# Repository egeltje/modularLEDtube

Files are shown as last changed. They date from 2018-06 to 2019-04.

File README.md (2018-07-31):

# modularLEDtube
A stackable tube with ws2812 LED's that can be combined to create an organ-like 
sculpture and display various light effects.

https://www.pjrc.com/store/teensy32.html
https://www.pjrc.com/store/octo28_adaptor.html

2 x https://www.xxlstunt.nl/product/plexiglas-buis--geextrudeerd-148/
8 x https://www.xxlstunt.nl/product/afvoer-pvc-bocht-45---mof-spie-3/
8 x https://www.xxlstunt.nl/product/afvoer-pvc-t-stuk-90---verloop-mof-spie-5/
2 x https://www.xxlstunt.nl/product/afvoer-pvc-eindstuk-met-schroefdeksel--spie-5/
2 x https://www.xxlstunt.nl/product/afvoer-pvc-buis-sn4-1/

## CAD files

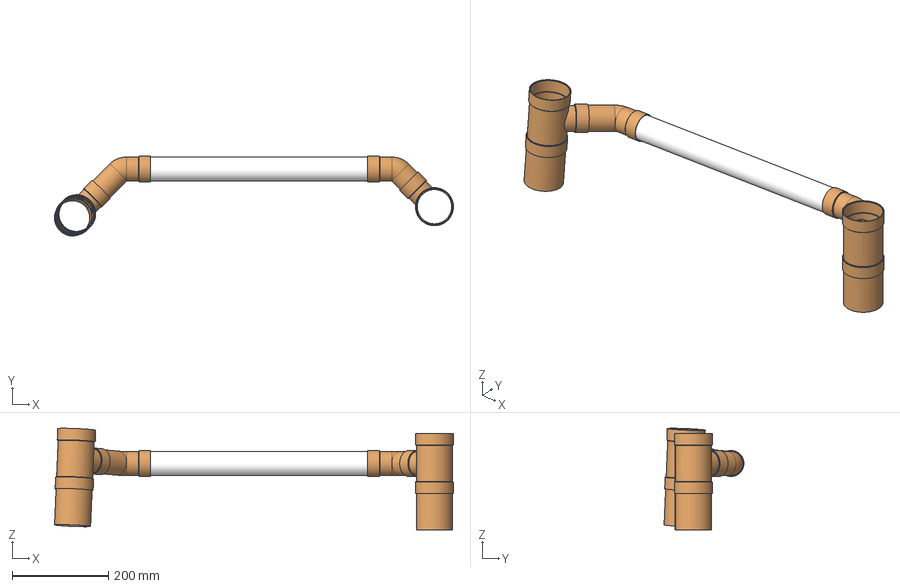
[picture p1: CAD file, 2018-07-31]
cad/overview.FCStd
827.3 x 165.8 x 210.6 mm
L_50_01
L_50_01001
tube_transparent_50x500_01
T_75x50_01
T_75x50_01001
tube_solid_75x100_01
tube_solid_75x100_01001

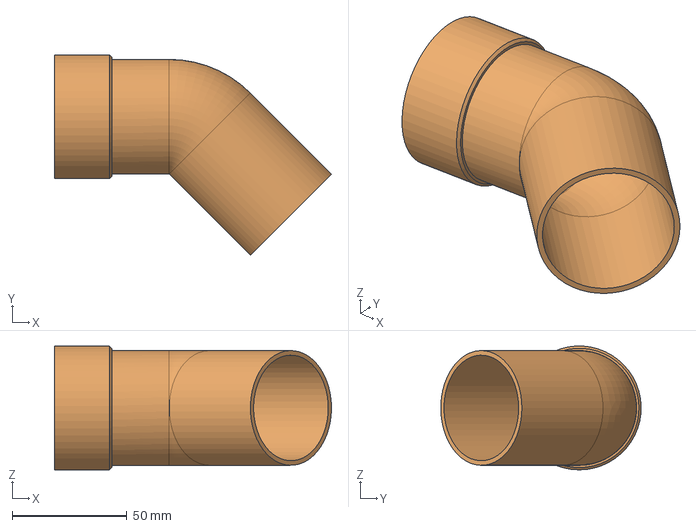
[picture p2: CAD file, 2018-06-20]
cad/L-50.FCStd
120.7 x 87.3 x 53.9 mm

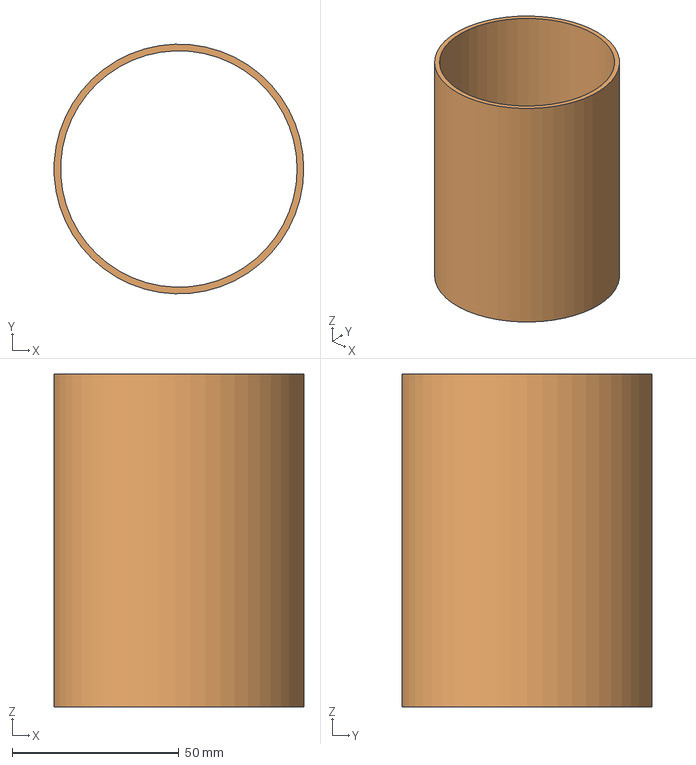
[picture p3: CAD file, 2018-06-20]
cad/tube-solid-75x100.FCStd
74.9 x 75.0 x 100.0 mm

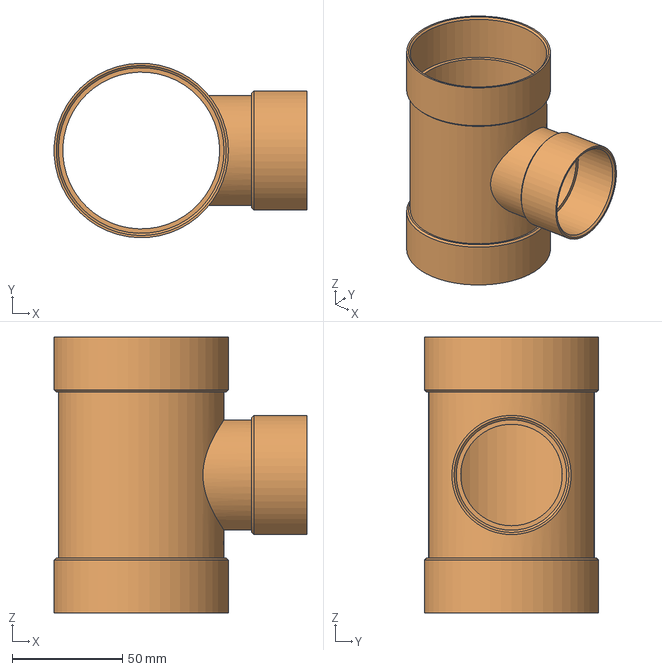
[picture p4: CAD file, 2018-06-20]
cad/T-75x50.FCStd
114.4 x 79.0 x 125.0 mm

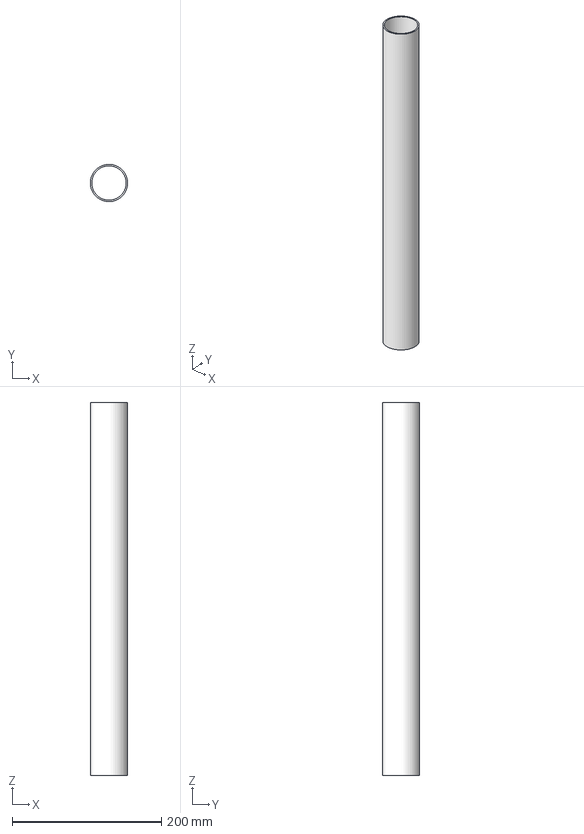
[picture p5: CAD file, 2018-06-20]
cad/tube-transparent-50x500.FCStd
50.0 x 50.0 x 500.0 mm

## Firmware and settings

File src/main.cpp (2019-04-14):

#include <Arduino.h>
#include "FastLED.h"
#include <stdint.h>
#include "main.h"

void setup() {
  // configure serial ports
  // Serial.begin(115200);
  // Serial1.begin(9600);

  // configure lED strips in FastLED array
  FastLED.addLeds<CHIPSET, LED_PIN0, COLOR_ORDER>(leds[0], NUM_LEDS).setCorrection( TypicalLEDStrip );
  FastLED.addLeds<CHIPSET, LED_PIN1, COLOR_ORDER>(leds[1], NUM_LEDS).setCorrection( TypicalLEDStrip );
  FastLED.addLeds<CHIPSET, LED_PIN2, COLOR_ORDER>(leds[2], NUM_LEDS).setCorrection( TypicalLEDStrip );
  FastLED.addLeds<CHIPSET, LED_PIN3, COLOR_ORDER>(leds[3], NUM_LEDS).setCorrection( TypicalLEDStrip );
  FastLED.addLeds<CHIPSET, LED_PIN4, COLOR_ORDER>(leds[4], NUM_LEDS).setCorrection( TypicalLEDStrip );
  FastLED.addLeds<CHIPSET, LED_PIN5, COLOR_ORDER>(leds[5], NUM_LEDS).setCorrection( TypicalLEDStrip );
  FastLED.addLeds<CHIPSET, LED_PIN6, COLOR_ORDER>(leds[6], NUM_LEDS).setCorrection( TypicalLEDStrip );
  FastLED.addLeds<CHIPSET, LED_PIN7, COLOR_ORDER>(leds[7], NUM_LEDS).setCorrection( TypicalLEDStrip );

  delay(100); // sanity delay

  // Initialize Perlin coordinates to some random values
  x = random16();
  y = random16();
  z = random16();
}

void loop()
{
  // Add entropy to random number generator; we use a lot of it.
  random16_add_entropy(random());

  EVERY_N_MILLISECONDS(FRAME_DELAY) {
    // read potmeters and determine state
    Param1 = ReadPot(POT_EFFECT);
    Param2 = ReadPot(POT_EFFECT_MOD1);
    Param3 = ReadPot(POT_EFFECT_MOD2);
    Param4 = ReadPot(POT_EFFECT_MOD3);
    State = ReadState(Param1);

    // run simulation frame depending on state
    switch (State) {
      case 2:
        Light(Param2, Param3, Param4);
        break;
      case 3:
        Color(Param2, Param3, Param4);
        break;
      case 4:
        Earth(Param2, Param3, Param4);
        break;
      case 5:
        Water(Param2, Param3, Param4);
        break;
      case 6:
        Fire(Param2, Param3, Param4);
        break;
      case 7:
        Air(Param2, Param3, Param4);
        break;
      default:
        Rainbow(Param2, Param3, Param4);
    }
    // display the calculated frame
    FastLED.show();
  }
}

void Light(uint8_t Param2, uint8_t Param3, uint8_t Param4) {
  // Param2 not used
  // Param3 not used
  // Param4 brightness
  uint8_t i, j;

  for (i = 0; i < NUM_STRIPS; i++) {
    for (j = 0; j < NUM_LEDS; j++) {
      leds[i][j] = 0xFFFFFF;
    }
  }
  FastLED.setBrightness(Param4);
}

void Color(uint8_t Param2, uint8_t Param3, uint8_t Param4) {
  // Param2 Hue
  // Param3 Saturation
  // Param4 Value
  uint8_t i, j;
  CRGB rgb;
  CHSV hsv(Param2, Param3, Param4);

  hsv2rgb_spectrum(hsv, rgb);

  for (i = 0; i < NUM_STRIPS; i++) {
    for (j = 0; j < NUM_LEDS; j++) {
      leds[i][j] = rgb;
    }
  }
}

void Earth(uint8_t Param2, uint8_t Param3, uint8_t Param4) {
  // Param2 Density
  // Param3 Level
  // Param4 Brightness
  static uint8_t solid[NUM_STRIPS][NUM_LEDS];
  uint8_t i, j;
  int iOffset, jOffset;

  for (i = 0; i < NUM_STRIPS; i++) {
    iOffset = i * Param2;
    for (j = 0; j < (NUM_LEDS / (255 / Param3)); j++) {
      jOffset = j * Param2;
      solid[i][j] = inoise8(x + iOffset, y + jOffset, (Param2 * 10));
    }
    for(j = 0; j < NUM_LEDS; j++) {
      leds[i][j] = ColorFromPalette((CRGBPalette16)earth_gp, solid[i][j]);
    }
  }
  FastLED.setBrightness(Param4);
}

void Water(uint8_t Param2, uint8_t Param3, uint8_t Param4) {
  // Param2 Waves
  // Param3 Level
  // Param4 Brightness
  static uint8_t liquid[NUM_STRIPS][NUM_LEDS];
  uint8_t i, j;
  int iOffset, jOffset;

  for (i = 0; i < NUM_STRIPS; i++) {
    iOffset = i * Param2;
    for (j = 0; j < (uint8_t)((Param2 * NUM_LEDS) / 255); j++) {
      jOffset = j * Param2;
      liquid[i][j] = inoise8(x + iOffset, y + jOffset, z);
    }
    for (j = (uint8_t)((Param3 * NUM_LEDS) / 255) + 1; j < NUM_LEDS; j++) {
      liquid[i][j] = 0;
    }
    z++; // move through the Perlin noise
    for(j = 0; j < NUM_LEDS; j++) {
      leds[i][j] = ColorFromPalette((CRGBPalette16)water_gp, liquid[i][j]);
    }
  }
  FastLED.setBrightness(Param4);
}

void Fire(uint8_t Param2, uint8_t Param3, uint8_t Param4) {
  // Param2 Sparkling
  // Param3 Cooling
  // Param4 brightness
  // Inspired by Fire2012 by Mark Kriegsman, July 2012
  // as part of "Five Elements" shown here: http://youtu.be/knWiGsmgycY

  static uint8_t heat[NUM_STRIPS][NUM_LEDS];
  uint8_t i, j;

  for (i = 0; i < NUM_STRIPS; i++) {
    // Step 1.  Cool down every cell a little
    for(j = 0; j < NUM_LEDS; j++) {
      heat[i][j] = qsub8(heat[i][j],  random8(0, ((Param3 * 10) / NUM_LEDS) + 2));
    }
    // Step 2.  Heat from each cell drifts 'up' and diffuses a little
    for(j = NUM_LEDS - 1; j >= 2; j--) {
      heat[i][j] = (heat[i][j - 1] + heat[i][j - 2] + heat[i][j - 2] ) / 3;
    }
    // Step 3.  Randomly ignite new 'sparks' of heat near the bottom
    if(random8() < Param2) {
      j = random8(7);
      heat[i][j] = qadd8(heat[i][j], random8(160,255));
    }
    // Step 4.  Map from heat cells to LED colors
    for(j = 0; j < NUM_LEDS; j++) {
      leds[i][j] = HeatColor(heat[i][j]);
//      leds[i][j] = ColorFromPalette((CRGBPalette16)fire_gp, heat[i][j]);
    }
  }
  FastLED.setBrightness(Param4);
}

void Air(uint8_t Param2, uint8_t Param3, uint8_t Param4) {
  // Param2 Bubbling
  // Param3 not used
  // Param4 Brightness
  static uint8_t gas[NUM_STRIPS][NUM_LEDS];
  uint8_t i, j;

  for (i = 0; i < NUM_STRIPS; i++) {
    // rise all bubbles
    for(j = NUM_LEDS - 1; j >= 1; j--) {
      gas[i][j] = gas[i][j - 1];
    }
    // Generate new bubbles at random
    if(random8() < (Param2/8)) {
      gas[i][0] = 0;
      gas[i][1] = 127;
      gas[i][2] = 255;
    }
    for(j = 0; j < NUM_LEDS; j++) {
      leds[i][j] = ColorFromPalette((CRGBPalette16)air_gp, gas[i][j]);
    }
  }
  FastLED.setBrightness(Param4);
}

void Rainbow(uint8_t Param2, uint8_t Param3, uint8_t Param4) {
  // Param2 not used
  // Param3 not used
  // Param4 Brightness
  static uint8_t Gradient;
  uint8_t i;

  if (Gradient < RAINBOW_STEP) {
    Gradient = 255;
  } else {
    Gradient -= RAINBOW_STEP;
  }

  for (i = 0; i < NUM_STRIPS; i++) {
    fill_rainbow(leds[i], NUM_LEDS, ((i * 20 + Gradient) % 255), 4);
  }
  FastLED.setBrightness(Param4);
}

uint16_t ReadPot(uint8_t Channel) {
  return analogRead(Channel) / 4;
}

uint8_t ReadState(uint8_t Value) {
  return scale8(Value, 9);
}

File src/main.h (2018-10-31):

#define LED_PIN0           2
#define LED_PIN1          14
#define LED_PIN2           7
#define LED_PIN3           8
#define LED_PIN4           6
#define LED_PIN5          20
#define LED_PIN6          21
#define LED_PIN7           5

#define TX1_PIN            1
#define RX1_PIN            0

#define POT_EFFECT_MOD3    3  // original channel 5 pin 17
#define POT_EFFECT_MOD2    4  // original channel 4 pin 18
#define POT_EFFECT_MOD1    5  // original channel 3 pin 19
#define POT_EFFECT         8  // original channel 8 Pin 22
#define POT_SPARE          9  // original channel 9 pin 23

#define COLOR_ORDER      GRB
#define CHIPSET       WS2812
#define NUM_LEDS          48
#define NUM_STRIPS         8

#define FRAME_DELAY       40

#define RAINBOW_STEP       4

CRGB leds[NUM_STRIPS][NUM_LEDS];

DEFINE_GRADIENT_PALETTE( earth_gp ) {
  0,   0,   0,   0,
127,  31,   0,   0,
255, 127, 127,   0
};
DEFINE_GRADIENT_PALETTE( water_gp ) {
  0,   0,   0,   0,
  1,   0,  63,   0,
127,   0,  63, 127,
223,   0, 223, 127,
255, 127, 255, 255
};
DEFINE_GRADIENT_PALETTE( fire_gp ) {
  0,   0,   0,   0,
 63, 255,   0,   0,
127, 255, 255,   0,
255, 255, 255, 255
};
DEFINE_GRADIENT_PALETTE( air_gp ) {
  0,   0,   0,   0,
255, 127, 255, 255
};

static uint16_t x;
static uint16_t y;
static uint16_t z;
uint8_t State;
uint8_t Param1, Param2, Param3, Param4;

void Light(uint8_t Param2, uint8_t Param3, uint8_t Param4);
void Color(uint8_t Param2, uint8_t Param3, uint8_t Param4);
void Earth(uint8_t Param2, uint8_t Param3, uint8_t Param4);
void Water(uint8_t Param2, uint8_t Param3, uint8_t Param4);
void Fire(uint8_t Param2, uint8_t Param3, uint8_t Param4);
void Air(uint8_t Param2, uint8_t Param3, uint8_t Param4);
void Rainbow(uint8_t Param2, uint8_t Param3, uint8_t Param4);

uint16_t ReadPot(uint8_t Channel);
uint8_t ReadState(uint8_t Value);

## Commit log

2018-06-18 Initial CAD file created
    [tube.FCStd]
2018-06-19 Added CAD T-section 75x50 mm
    [T-75x50.FCStd]
2018-06-20 Added CAD L-section 50 mm
    [L-50.FCStd]
2018-06-20 Added CAD tube sections
    [tube-solid-75x100.FCStd, tube-transparent-50x500.FCStd]
2018-06-20 Added additional sleeve to CAD T-section 75x50
    [T-75x50.FCStd]
2018-06-20 Removed chamfer from CAD tube sections for better assembly
    [L-50.FCStd, T-75x50.FCStd, tube-solid-75x100.FCStd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]
2018-06-25 Moved platform from esp to teensy.
2018-06-25 Removed generic tube for specific tubes
    [tube.FCStd]
2018-06-25 Removed ESP32-DOIT platfrom
2018-06-25 Initial Fire2012 code for testing one LED strip on pin 2
2018-06-25 Added board LED to turn on if the program is active
2018-06-26 Added input pins for connecting switches
2018-06-28 Switched static light to yellow
2018-07-15 Added flow to the rainbow element
2018-07-17 Modified earth and water element to construct frame and push it to leds using the same method as the other elements
2018-07-30 Made functions more uniform and changed number of leds to 48
2018-07-31 Added to readme.md
    [overview.FCStd]
2018-08-15 Changed water element from sine wave to perlin noise function
    [main.cpp, main.h]
2018-08-17 Updated earth element using noise
    [main.cpp, main.h]
2018-08-21 Fixed water heigt algorithm
    [main.cpp, main.h]
2018-10-27 Added different flow offset to the Rainbow effect
2019-04-14 Switched from Atom_platformio to VSC_platformio
